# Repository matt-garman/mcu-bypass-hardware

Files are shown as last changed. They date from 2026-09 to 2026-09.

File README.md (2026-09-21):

<!-- SPDX-License-Identifier: CERN-OHL-P-2.0 -->

# MCU Hardware for Switch Debounce and Electric Instrument Effects Switching

## Overview

This is the companion repo to [mcu-bypass-firmware](https://github.com/matt-garman/mcu-bypass-firmware).

These hardware designs are intended to be used for electric
instrument effects (e.g. guitar effect pedals) bypass switching.
Many of these schemes rely on a microcontroller to act as the
"brains" of the switching scheme; see the other repo for MCU
firmware.

## License

Copyright (c) 2026 Matthew Garman

These hardware designs (schematics, PCB layouts, fabrication files,
documentation, and supporting scripts) are licensed under the
[CERN Open Hardware Licence Version 2 - Permissive](LICENSE)
(SPDX: `CERN-OHL-P-2.0`). The companion firmware is licensed separately
under the MIT License; see that repo for details.

In short, you may use, modify, and share these designs, and make and
sell products based on them, including commercial products. The main
condition is keeping the copyright and license notices available to
whoever receives the design files or a product built from them. The
designs are provided as-is, WITHOUT ANY WARRANTY; see the
[license](LICENSE) for the actual terms.

## Credit (appreciated, not required)

If you use these designs or the firmware in something you build, and
especially in something you sell, a shout-out would be much appreciated.
A line in your manual, product page, or "About" screen is perfect.
For example:

> Bypass switching based on [mcu-bypass-hardware](https://github.com/matt-garman/mcu-bypass-hardware)
> and [mcu-bypass-firmware](https://github.com/matt-garman/mcu-bypass-firmware)
> by Matt Garman.

You have my permission to use my name this way to credit these
projects. Please don't word it in a way that suggests I endorse, or
was involved with, your product.

## Projects

  - [projects/attiny13a-buffered-electrical-bypass-quasi-ic](projects/attiny13a-buffered-electrical-bypass-quasi-ic/)
  - [projects/attiny202-buffered-electrical-bypass-quasi-ic](projects/attiny202-buffered-electrical-bypass-quasi-ic/)

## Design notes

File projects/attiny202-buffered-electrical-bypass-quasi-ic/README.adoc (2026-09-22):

// SPDX-License-Identifier: CERN-OHL-P-2.0

= ATtiny202 Buffered Electrical Bypass Quasi-IC

== Overview

See the sister project
link:../attiny13a-buffered-electrical-bypass-quasi-ic/[attiny13a-buffered-electrical-bypass-quasi-ic]
for a detailed discussion of this design.  The design intent and
functionality of the two modules are identical.  That is, this
module is intended to offer the same "plug and play" convenience of
an integrated circuit, one that offers analog signal
buffering and switching, as well as engage/bypass state management
and status LED lighting/darking.

The differences are:

  * This project uses the ATtiny202 microcontroller, whereas the
    other uses ATtiny13a.  The actual firmware behavior is the same;
    the source itself differs only in the obligatory
    hardware-specific details.
  * This PCB design is much smaller, with a 43x16mm footprint
  * This design is a 4-layer PCB, whereas the other is 2-layer
  * This PCB uses a single row of pin headers to enable _vertical_
    mounting (i.e. perpendicular to the parent PCB) using
    right-angle pin headers (credit to
    link:https://www.diystompboxes.com/smfforum/index.php?msg=1312371[RG Keen for the suggestion])

== Schematic

link:attiny202-quasi-ic.pdf[Downloadable PDF]



== Module Pinout

The module plugs into its parent PCB through a single row of nine
pins, 2.54 mm pitch.  The pins are numbered 1 through 9,
left-to-right, as viewed from the component side.

....
   1 | 2 | 3 | 4 | 5 | 6 | 7 | 8 | 9
  VDC|GND|JIN|SND|LSW|RET|JOU|GND|FSW
....

[cols="1,2,6",options="header"]
|===
| Pin | Signal | Description

| 1
| VDC
| Supply input; the module has a reverse-polarity shunt diode (D2)
and a 22-ohm series resistor (R5) on this pin

| 2, 8
| GND
| Ground (0-volt)

| 3
| JIN
| Signal input, from the input jack; goes to the input buffer

| 4
| SND
| Buffered signal to the effect circuit's input, switched by the
TMUX4053 and AC-coupled (C10)

| 5
| LSW
| Status LED cathode, switched to ground by Q3 through a 4.7k-ohm
resistor (R26) on the module.  Connect the LED's anode to the supply;
the parent PCB _may_ need additional current-limiting resistance,
depending on desired LED brightness and/or LED type (I typically add
an additional 3.3k-ohm for ultrabright/high-efficiency LEDs)

| 6
| RET
| The effect circuit's output, returning to the module; AC-coupled
(C9)

| 7
| JACK_OUT
| Buffered signal output, to the output jack

| 9
| FSW
| Momentary, normally-open footswitch to ground; the pull-up, ferrite
bead, RC filter and ESD protection are on the module
|===

// TODO: supply voltage range and typical current draw.

== Modifying

The KiCad project is
link:attiny202-quasi-ic.kicad_pro[attiny202-quasi-ic.kicad_pro],
in this directory.  KiCad version 10.0.5 was used.

== Build Reports

  * link:https://forum.pedalpcb.com/threads/nashville-nobility-custom-nobels-odr-1bc.30339/[Nashville Nobility]
  * link:https://forum.pedalpcb.com/threads/the-enchanter-custom-timmy-jan-ray.30400/[The Enchanter]

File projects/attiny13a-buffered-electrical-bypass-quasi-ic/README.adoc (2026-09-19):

// SPDX-License-Identifier: CERN-OHL-P-2.0

= ATtiny13A Buffered Electrical Bypass Quasi-IC

== Background

After several years of building effects pedals, I've converged on a
personal favorite bypass scheme: electrical analog switching with
control by a microcontroller, along with buffered input and output.
This is conceptually similar to most Boss compact pedals (although
they tend to use discrete JFETs for the input buffer and actual
circuit switching, the logic is a discrete "crossbar"-BJT scheme,
and the output buffer is typically a BJT).

I typically design through-hole effect PCBs; however, my preferred
bypass scheme consumes a fair amount of PCB space: two 8-pin DIP ICs
(opamp buffers, MCU), a 16-pin DIP switching IC (CD4053), and all
the supporting circuitry.  Besides the PCB footprint, it's also a
_time_ cost, as I often end up tweaking the bypass layout to match
with the actual effect layout.

I thought to myself, it would be nice to have a single integrated
circuit that did what I wanted, that I could use in a plug-and-play
fashion.  This would save PCB space and layout time.  Of course, no
such IC exists, so I did the next-best thing and tried to make a
small, surface-mount based PCB that could be used just like an IC -
so I call it a "quasi-IC".  With PCB fabrication and SMD assembly
done via contract, I can now keep an inventory of small
plug-and-play PCBs that mate to the parent PCB.

This project represents my initial working prototype of the
quasi-IC.

== Schematic

link:attiny13a-quasi-ic.pdf[Downloadable PDF]



== Module Pinout

The module plugs into its parent PCB through two rows of five pins,
2.54 mm pitch, with the rows 31.00 mm apart.  The pins are numbered
like a DIP IC: counter-clockwise from pin 1, viewed from the
component side.

....
                +-----------+
       JACK_IN  | 1      10 |  JACK_OUT
           GND  | 2       9 |  EFFECT_PCB_OUT
           +9V  | 3       8 |  GND
           GND  | 4       7 |  LED_CATHODE
 EFFECT_PCB_IN  | 5       6 |  FOOTSW_RAW
                +-----------+
....

[cols="1,2,6",options="header"]
|===
| Pin | Signal | Description

| 1
| JACK_IN
| Signal input, from the input jack; goes to the input buffer

| 2, 4, 8
| GND
| Ground (0-volt)

| 3
| +9V
| Supply input; the module has a reverse-polarity shunt diode (D2)
and a 22 Ω series resistor (R5) on this pin

| 5
| EFFECT_PCB_IN
| Buffered signal to the effect circuit's input, switched by the
TMUX4053 and AC-coupled (C10)

| 6
| FOOTSW_RAW
| Momentary, normally-open footswitch to ground; the pull-up, ferrite
bead, RC filter and ESD protection are on the module

| 7
| LED_CATHODE
| Status LED cathode, switched to ground by Q3 through a 4.7 kΩ
resistor (R26) on the module.  Connect the LED's anode to the supply;
the parent PCB _may_ need additional current-limiting resistance,
depending on desired LED brightness and/or LED type (I typically add
an additional 3.3 kΩ for ultrabright/high-efficiency LEDs)

| 9
| EFFECT_PCB_OUT
| The effect circuit's output, returning to the module; AC-coupled
(C9)

| 10
| JACK_OUT
| Buffered signal output, to the output jack
|===

// TODO: supply voltage range and typical current draw.

== Design Overview

The "brains" of this module is a SOIC-8 ATtiny13A microcontroller.
The MIT-licensed firmware - including design documentation and an
extensive test and validation suite - is available here:
https://github.com/matt-garman/mcu-bypass-firmware[mcu-bypass-firmware].

Input and output buffering is provided by an OPA1678 opamp in a
WSON-8 package.  This is a modern high-quality opamp whose
specifications surpass effectively all readily available
through-hole opamps.  It should have no audible impact on the
signal.  Using this opamp at the effect's input provides for a
consistently high impedance (effectively zero load for even
low-output guitar pickups).  Using the other half at the effect's
output provides for a consistently low impedance, to easily drive
the next effect in the chain, a long cable, or the amp itself.

Actual signal switching is done by the TMUX4053, which is an
upgraded version of the CD4053, only available in surface mount;
here I'm using the 16-pin TSOT-23 (TI "DYY") version.

The module is wired for the "4053 with mute" scheme: the MCU
firmware implementation plus circuit wiring create three distinct
states: bypass, engage, mute.  When responding to a footswitch
press, the MCU first switches the TMUX4053 to the mute state for
five milliseconds, then switches to engage or bypass.  The brief
muting seeks to minimize or even eliminate popping often associated
with engage/bypass switching.

The MCU and TMUX4053 control signals run at 5v.  The 5v supply is
provided by the AP7375 LDO.  This is a modern regulator with a _very_
low dropout voltage and extremely low quiescent current.

The design takes a "belt-and-suspenders" approach to footswitch
debounce and EMI/RFI resiliency:

* the footswitch hardware wiring includes a ferrite bead and an
  RC filter
* the ATtiny13A has Schmitt Trigger inputs
* the actual debounce algorithm implemented in firmware is
  abstracted into a provably-correct _pure_ implementation; the
  actual firmware has been exhaustively tested to survive all
  but the most adverse/unusual circumstances

== Modifying

The KiCad project is
link:attiny13a-quasi-ic.kicad_pro[attiny13a-quasi-ic.kicad_pro],
in this directory.  KiCad version 10.0.5 was used.

== Build Reports

  * link:https://forum.pedalpcb.com/threads/dynamic-haircut-v2-0-barber-gain-changer.29479/post-393071[Dynamic Haircut v2.0]
  * link:https://forum.pedalpcb.com/threads/old-fashioned-skreddy-animals-major-overdrive.28763/post-395652[Old Fashioned v2.0]

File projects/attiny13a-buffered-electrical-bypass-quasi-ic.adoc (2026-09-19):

// SPDX-License-Identifier: CERN-OHL-P-2.0

= ATtiny13A Buffered Electrical Bypass Quasi-IC

== Background

After several years of building effects pedals, I've converged on a
personal favorite bypass scheme: electrical analog switching with
control by a microcontroller, along with buffered input and output.
This is conceptually similar to most Boss compact pedals (although
they tend to use discrete JFETs for the input buffer and actual
circuit switching, the logic is a discrete "crossbar"-BJT scheme,
and the output buffer is typically a BJT).

I typically design through-hole effect PCBs; however, my preferred
bypass scheme consumes a fair amount of PCB space: two 8-pin DIP ICs
(opamp buffers, MCU), a 14-pin DIP switching IC (CD4053), and all
the supporting circuitry.  Besides the PCB footprint, it's also a
_time_ cost, as I often end up tweaking the bypass layout to match
with the actual effect layout.

I thought to myself, it would be nice to have a single integrated
circuit that did what I wanted, that I could use in a plug-and-play
fashion.  This would save PCB space and layout time.  Of course, no
such IC exists, so I did the next-best thing and tried to make a
small, surface-mount based PCB that could be used just like an IC -
so I call it a "quasi-IC".  With PCB fabrication and SMD assembly
done via contract, I can now keep an inventory of small
plug-and-play PCBs that mate to the parent PCB.

This project represents my initial working prototype of the
quasi-iC.

== Schmatic

link:attiny13a-buffered-electrical-bypass-quasi-ic/attiny13a-quasi-ic.pdf[Downloadable PDF]



== Design Overview

The "brains" of this module is a SOIC-8 ATtiny13A microcontroller.
The MIT-licensed firmware - including design documentation and an
extensive test and validation suite - is available here:
[mcu-bypass-firmware](https://github.com/matt-garman/mcu-bypass-firmware).

Input and output buffering is provided by an OPA1678 opamp in a
WSON-8 package.  This is modern high-quality opamp whose
specifications surpass effectively all readily available
through-hole opamps.  It should have no audible impact on the
signal.  Using this opamp at the effect's input provides for a
consistently high impedance (effectively zero load for even
low-output guitar pickups).  Using the other half at the effect's
output provides for a consistently low impedance, to easily drive
the next effect in the chain, a long cable, or the amp itself.

Actual signal switching is done by the TMUX4053, which is an
upgraded version of the CD4053, only available in surface mount;
here I'm using the SOT-14 version.

The module is wired for the "4053 with mute" scheme: the MCU
firmware implementation plus circuit wiring create three distinct
states: bypass, engage, mute.  When responding to a footswitch
press, the MCU first switches the TMUX4053 to the mute state for
five milliseconds, then switches to engage or bypass.  The brief
muting seeks to minimize or even eliminate popping often associated
with engage/bypass switching.

The MCU and TMUX4053 control signals run at 5v.  The 5v supply is
provided by the AP7375 LDO.  This a modern regulator with a _very_
low dropout voltage and extremely low quiescent current.

The design takes a "belt-and-suspenders" approach to footswitch
debounce and EMI/RFI resiliency:
    * the footswitch hardware wiring includes a ferrite bead and an
      RC filter
    * the ATtiny13A has Schmitt Trigger inputs
    * the actual debounce algorithm implemented in firmware is
      abstracted into a provably-correct _pure_ implementation; the
      actual firmware has been exhaustively tested to survive all
      but the most adverse/unusual circumstances

== Modifying

The KiCad files are in
`attiny13a-buffered-electrical-bypass-quasi-ic`.  KiCad version
10.0.5 was used.

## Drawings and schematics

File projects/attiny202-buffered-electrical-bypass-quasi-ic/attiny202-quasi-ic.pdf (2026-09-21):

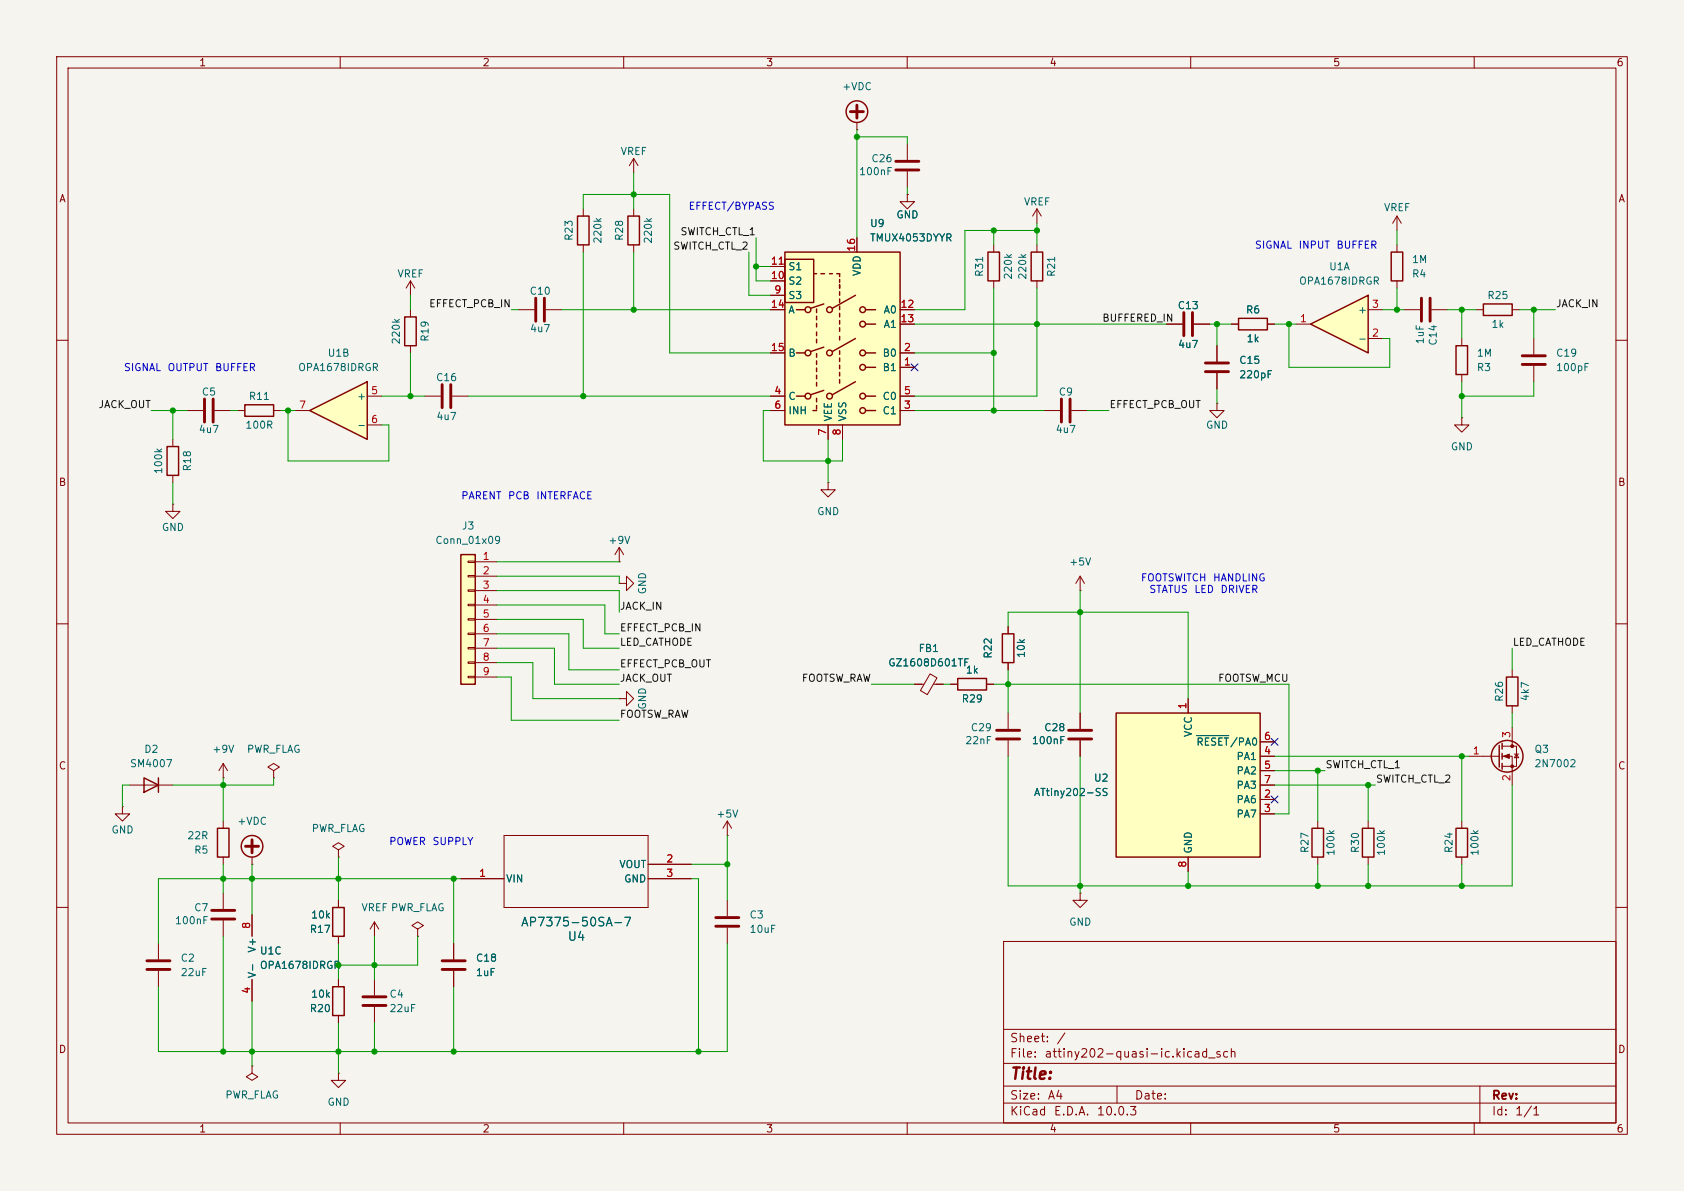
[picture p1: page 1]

EFFECT_PCB_OUT EFFECT/BYPASS PARENT PCB INTERFACE SIGNAL OUTPUT BUFFER

Size: A4 | Rev:
KiCad E.D.A. 10.0.3 | Id: 1/1

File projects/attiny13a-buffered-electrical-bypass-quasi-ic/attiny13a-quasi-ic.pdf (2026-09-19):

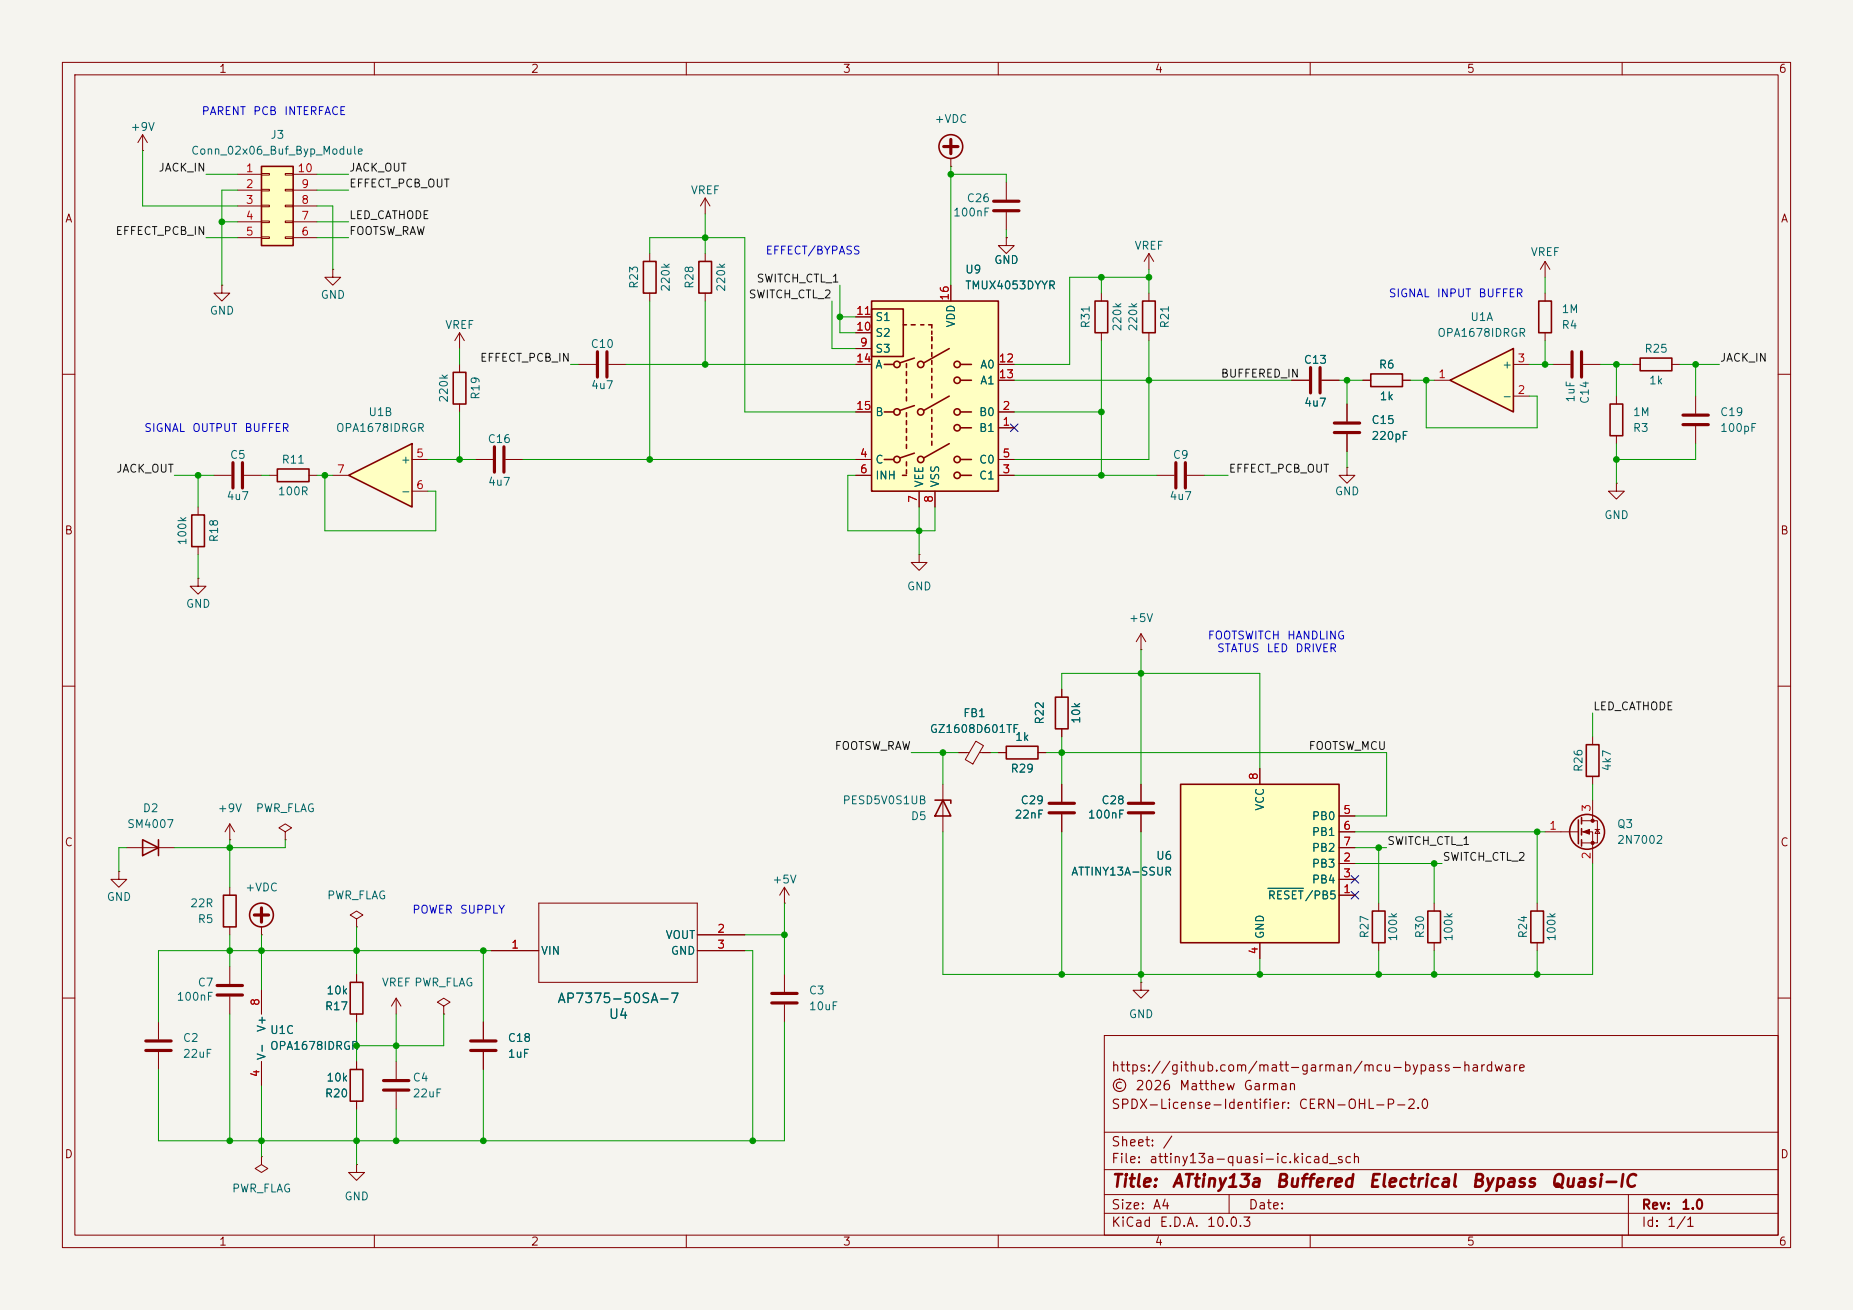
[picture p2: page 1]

EFFECT/BYPASS PARENT PCB INTERFACE SIGNAL OUTPUT BUFFER

https://github.com/matt-garman/mcu-bypass-hardware
© 2026 Matthew Garman
SPDX-License-Identifier: CERN-OHL-P-2.0

Sheet: /
File: attiny13a-quasi-ic.kicad_sch
Title: ATtiny13a Buffered Electrical Bypass Quasi-IC

Size: A4 | Rev: 1.0
KiCad E.D.A. 10.0.3 | Id: 1/1

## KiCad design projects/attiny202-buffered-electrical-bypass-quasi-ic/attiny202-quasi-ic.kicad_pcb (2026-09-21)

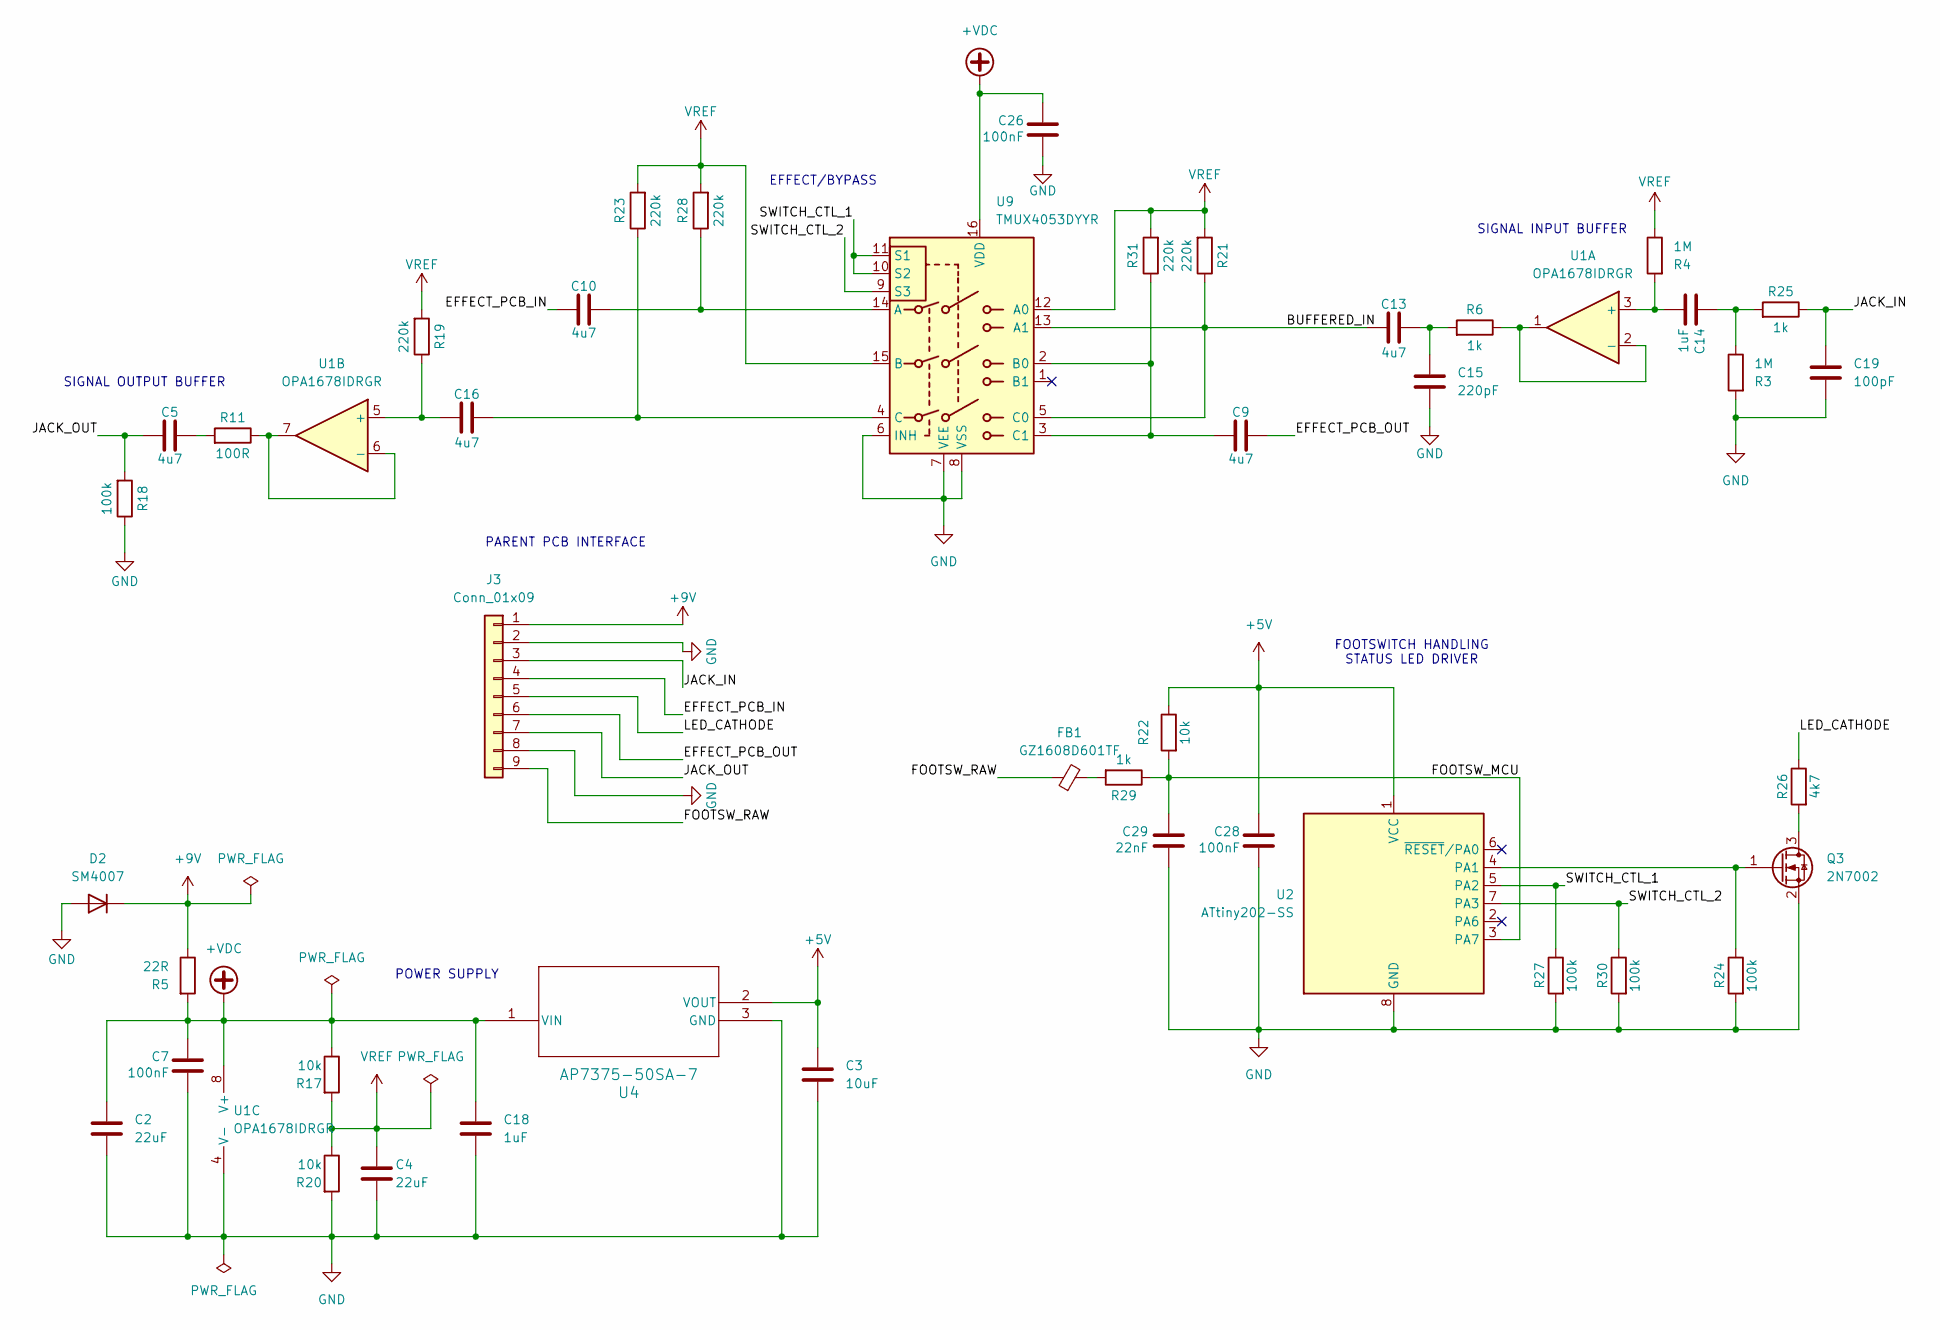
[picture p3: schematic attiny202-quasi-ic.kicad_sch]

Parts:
C2, C4: 22uF; C_1206_3216Metric; LCSC C12891
C3: 10uF; C_1206_3216Metric; LCSC C13585
C5, C9, C10, C13, C16: 4u7; C_1206_3216Metric; LCSC C29823
C7, C26, C28: 100nF; C_0603_1608Metric; LCSC C14663
C14, C18: 1uF; C_0805_2012Metric; LCSC C28323
C15: 220pF; C_0603_1608Metric; LCSC C1603
C19: 100pF; C_0603_1608Metric; LCSC C14858
C29: 22nF; C_0603_1608Metric; LCSC C21122
D2: SM4007; D_SOD-123F; LCSC C64898
FB1: GZ1608D601TF; L_0603_1608Metric; LCSC C1002
J3: Conn_01x09; OffboardWireHoles_1x09_P2.54mm
Q3: 2N7002; SOT-23; LCSC C8545
R3, R4: 1M; R_0603_1608Metric; LCSC C22935
R5: 22R; R_1206_3216Metric; LCSC C17958
R6, R25, R29: 1k; R_0603_1608Metric; LCSC C21190
R11: 100R; R_0603_1608Metric; LCSC C22775
R17, R20, R22: 10k; R_0603_1608Metric; LCSC C25804
R18, R24, R27, R30: 100k; R_0603_1608Metric; LCSC C25803
R19, R21, R23, R28, R31: 220k; R_0603_1608Metric; LCSC C22961
R26: 4k7; R_0603_1608Metric; LCSC C23162
U1: OPA1678IDRGR; WSON-8-1EP_3x3mm_P0.5mm_EP1.2x2mm; LCSC C2861885
U2: ATtiny202-SS; SOIC-8_3.9x4.9mm_P1.27mm; LCSC C2052951
U4: AP7375-50SA-7; SOT23_DIO; LCSC C6500991
U9: TMUX4053DYYR; Texas_DYY0016A_TSOT-23-16_2x4.2mm_P0.5mm; LCSC C22388988

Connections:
+5V: C3.2, C28.2, R22.1, U2.1 (VCC), U4.2 (VOUT)
+9V: D2.1 (K), J3.1, R5.1
+VDC: C2.2, C7.2, C18.2, C26.2, R5.2, R17.1, U1.8 (V+), U4.1 (VIN), U9.16 (VDD)
/BUFFERED_IN: C13.2, R21.1, U9.5 (C0), U9.13 (A1)
/EFFECT_PCB_IN: C10.1, J3.4
/EFFECT_PCB_OUT: C9.2, J3.6
/FOOTSW_MCU: C29.2, R22.2, R29.1, U2.3 (PA7)
/FOOTSW_RAW: FB1.1, J3.9
/JACK_IN: C19.2, J3.3, R25.1
/JACK_OUT: C5.2, J3.7, R18.2
/LED_CATHODE: J3.5, R26.1
/SWITCH_CTL_1: R27.1, U2.5 (PA2), U9.10 (S2), U9.11 (S1)
/SWITCH_CTL_2: R30.1, U2.7 (PA3), U9.9 (S3)
GND: C2.1, C3.1, C4.1, C7.1, C15.1, C18.1, C19.1, C26.1, C28.1, C29.1, D2.2 (A), J3.2, J3.8, Q3.2 (S), R3.2, R18.1, R20.2, R24.2, R27.2, R30.2, U1.4 (V-), U2.8 (GND), U4.3 (GND), U9.6 (INH), U9.7 (VEE), U9.8 (VSS)
unnamed: C5.1, R11.2
unnamed: C13.1, C15.2, R6.2
unnamed: C14.2, R3.1, R25.2
unnamed: FB1.2, R29.2
unnamed: Q3.3 (D), R26.2
unnamed: Q3.1 (G), R24.1, U2.4 (PA1)
unnamed: C14.1, R4.2, U1.3 (+)
unnamed: R6.1, U1.1, U1.2 (-)
unnamed: C16.2, R19.1, U1.5 (+)
unnamed: R11.1, U1.6 (-), U1.7
unnamed: C10.2, R28.1, U9.14 (A)
unnamed: C9.1, R31.1, U9.2 (B0), U9.3 (C1)
unnamed: C16.1, R23.1, U9.4 (C)
VREF: C4.2, R4.1, R17.2, R19.2, R20.1, R21.2, R23.2, R28.2, R31.2, U9.12 (A0), U9.15 (B)

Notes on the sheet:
PARENT PCB INTERFACE
SIGNAL INPUT BUFFER
EFFECT/BYPASS
FOOTSWITCH HANDLING STATUS LED DRIVER
SIGNAL OUTPUT BUFFER
POWER SUPPLY

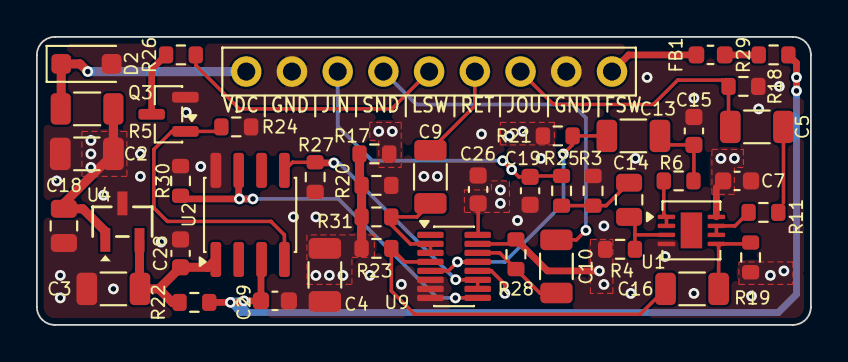
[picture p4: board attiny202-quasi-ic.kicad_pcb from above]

Board: 4 copper layers, 43.0 x 16.0 mm, 44 parts (0 on the bottom side), 28 nets.

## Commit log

2026-09-19 projects: initial commit w/attiny13a buffered electrical bypass quasi-ic
    [attiny13a-quasi-ic.kicad_pcb, attiny13a-quasi-ic.kicad_sch]
2026-09-19 add copyright and license
    [attiny13a-quasi-ic.kicad_pcb, attiny13a-quasi-ic.kicad_sch]
2026-09-19 Makefile: ERC-check and export schematics to PDF and SVG
    Add a top-level Makefile that finds every projects/<dir>/<name>.kicad_pro
    and, using kicad-cli:
    make runs ERC, then exports the root schematic as one
    multi-page PDF and one SVG per sheet
    make erc runs ERC only
    make clean removes build/
    Outputs go to build/<dir>/, which is gitignored: the exports embed a
    timestamp, so regenerated copies would always show up as changes. Copy
    them into a project when they're meant to be published.
    ERC fails the build on errors only; the exports depend on it passing.
    Errors and warnings together are also written to <name>-erc-all.rpt for
    review. Warnings don't fail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
2026-09-19 tiny13 quasi-ic: initial design doc, PDF and SVG schematics
2026-09-19 fix SVG schematic ref in design doc
2026-09-21 remove kicad_prl file
2026-09-21 add attiny202 buffered electrical bypass quasi-IC project
    [attiny202-quasi-ic.kicad_pcb, attiny202-quasi-ic.kicad_sch]
2026-10-18 add project attiny13a-relay-bypass-quasi-ic
2026-10-19 mcu relay bypass: add design notes; .gitignore kicad backup folder
2026-10-19 attiny13a relay: add fabrication files
2026-10-19 avr class relay: add NPN BJT notes
2026-10-19 avr classic relay module: fix pinout copy-paste errors
2026-10-19 avr classic relay module: more corrections
2026-10-19 Add AVR Classic relay bypass module BOM (PDF)
2026-10-19 avr classic relay module: add BOM in CSV and PDF formats
2026-10-19 avr classic relay module: add BOM in CSV format
